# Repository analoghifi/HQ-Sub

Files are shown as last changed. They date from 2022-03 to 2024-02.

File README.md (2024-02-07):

# HQ-Sub  
adjustable\* 5th order (**30 dB/oct.**) subsonic filter  
mono module  
\*(13-53Hz / in 2-3Hz steps / 16 steps)  
  
https://web.archive.org/web/20160324051200/http://thel-audioworld.de/module/Filterzone/HQ-Sub.htm

----  

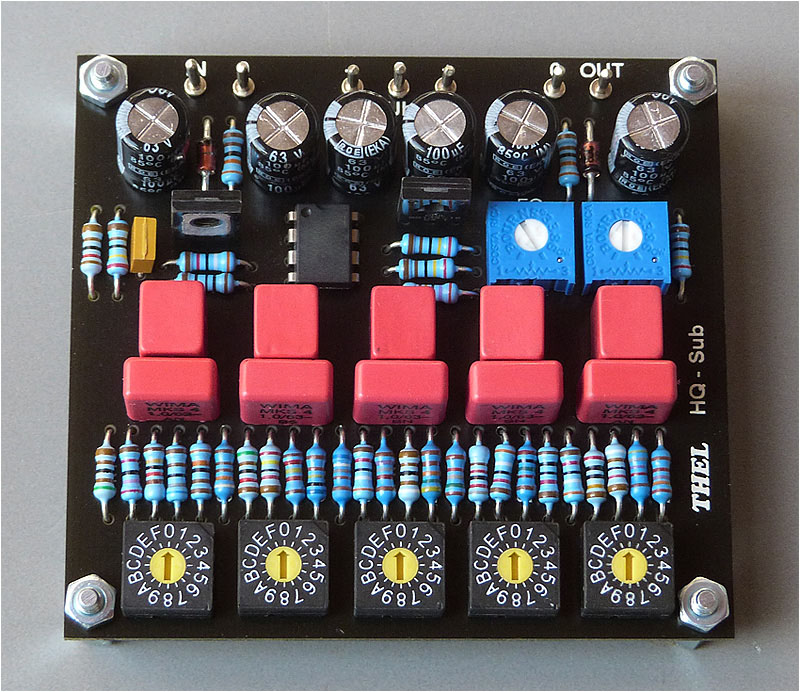
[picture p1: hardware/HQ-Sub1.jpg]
  
  
----  

### Frequency Table:  
* 0: 13Hz
* 1: 15Hz
* 2: 18Hz
* 3: 21Hz
* 4: 23Hz
* 5: 26Hz
* 6: 29Hz
* 7: 31Hz
* 8: 34Hz
* 9: 36Hz
* A: 39Hz
* B: 41Hz
* C: 44Hz
* D: 47Hz
* E: 50Hz
* F: 53Hz  

All 5 switches must always be in the same position (!)  
  
----  
  
### A note on the capacitors used in the original design  
The basic problem is:  
to get meaningful (= not too high) resistance values in this 5th order filter design we want to use 1µF capacitors.  
However, 1µF capacitors are generally not available in the KP film/foil version,  
at least not with a 1% tolerance and/or in suitable small dimensions for this small PCB.  
  
regarding C8-C17 in the original design:  
the 1µF MKS capacitors are paralleled with 22nF KP capacitors  
to compensate the very bad (=very high) dissipation factor (tanδ) of the MKS capacitors  
originally equipped with:  
WIMA MKS4    1µF/63V 10%   (Metallized Polyester (PET))     tanδ=8x10<sup>-3</sup> -> <a href="https://github.com/analoghifi/capacitors/blob/main/audio%20and%20filter%20capacitors/docs/datasheets/dont%20use/PET%20MKS/WIMA_MKS_4__EN.pdf">Datasheet</a>  
WIMA FKP2  0,022µF/63V 5%  (film/foil Polypropylene) tanδ=5x10<sup>-4</sup> -> <a href="https://github.com/analoghifi/capacitors/blob/main/audio%20and%20filter%20capacitors/docs/datasheets/kp/WIMA_FKP_2__NEW_ROHS__EN.pdf">Datasheet (ROHS-version)</a>  
(better old FKP2 version "NOS" without ROHS -> <a href ="https://github.com/analoghifi/capacitors/blob/main/audio%20and%20filter%20capacitors/docs/datasheets/kp/WIMA_FKP_2__OLD_nonROHS__EN.pdf">old Datasheet</a>)  
  
another problem is:  
You have to do a lot of component selection work (matching) when using 10% capacitors because:  
Even while it is not so important that the 5 filter capacitors have exactly 1.00 µF,  
they should at least all have the same value (±1%) among each other  
for this kind of 5th order filter arrangement.  
  
#### better alternative (better tolerance & better tanδ):
use good MKP 1% capacitors (with no additional parallel capacitors = omit C9,C11,C13,C15 and C17)  
**for example:**  
Vishay MKP1839 [MKP1839510161] 1µF/160V 1% axial (metallized Polypropylene) tanδ=4x10<sup>-4</sup> -> <a href="https://github.com/analoghifi/capacitors/blob/main/audio%20and%20filter%20capacitors/docs/datasheets/mkp/vishay_mkp1839.pdf">Datasheet</a> -> buy: https://mou.sr/3OpbFIe     
my KiCad PCB (<a href="/hardware/KiCad/original">/hardware/KiCad/original</a>) is prepared for using this big axial capacitors (10.5mm x 26.5mm) in upright position.  
**or another alternative:**  
Dayton Audio "PMPC-1.0 1.0uF 250V Precision Audio Capacitor" (metallized Polypropylene) with 1% tolerance as well   
-> https://www.daytonaudio.com/product/179/pmpc-1-0-1-0uf-250v-precision-audio-capacitor  
-> https://www.soundimports.eu/en/dayton-audio-pmpc-1-0.html  
-> https://www.parts-express.com/Dayton-Audio-PMPC-1.0-1.0uF-250V-Precision-Audio-Capacitor-027-210  
although not knowing the exact<sup>1</sup> tanδ for this type -> will be measured by me soon ...  
  
<sup>1</sup>(the manufacturer's statement: *"Dissipation Factor [tanδ]: Max 0.001 (0.1%) [10x10<sup>-4</sup>] @ 1 KHz"* is only a general worst case statement for the entire series of these capacitors.)
  
----  
### Kicad projects in this repo:  
* [Thel HQ-Sub](https://github.com/analoghifi/HQ-Sub/tree/main/hardware/KiCad/original) | state: initial release v1.01 | like the original, 1-layer, THT

----

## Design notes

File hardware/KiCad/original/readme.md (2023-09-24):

this is not the original Thel PCB but it's very like\* the original with the following exceptions:  
* more massive ground and power supply PCB tracks  
* using the 2mm gold-plated (lathe made) brass solder pins (the same ones used on the more expensive Thel modules)
* swapped positions for C1<->C5 and C2<->C6
* using a special footprint for the 1µF MKS foil caps (C8,C10,C12,C14,C16), so that you can use bigger (better) MKP axial caps in upright position (in this case: omit C9,C11,C13,C15 and C17)
  
\*(same schematic / same board dimensions / same 1-layer\** layout THT / same THT components in the same places on the board)  
\**(strictly speaking, this KiCad PCB is a two-layer PCB with plated-through holes, but you can also (let) produce it as a classic 1-layer PCB with non-plated holes if you wish, since all the tracks are on the bottom side only)  
    
----  
  
### remarks:  
#### U1:  
instead of [MC33078](https://github.com/analoghifi/HQ-Sub/blob/main/docs/components%20datasheet/MC33078_Motorola.pdf) you can use [LME49720](https://github.com/analoghifi/HQ-Sub/blob/main/docs/components%20datasheet/LME49720.pdf) or [LM4562](https://github.com/analoghifi/HQ-Sub/blob/main/docs/components%20datasheet/LM4562.pdf) (both\* Texas Instruments),  
with slightly better technical data regarding noise and THD.  
\*(these two are 100% identical (even regarding their inner guts))  

----  
  
these are KiCad 6.x projects  
see how to get the proper 3D-Models from here: https://github.com/analoghifi/KiCad-3D-Models

----  
  
use kicanvas.org to view this KiCad project in your browser:  
https://kicanvas.org/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

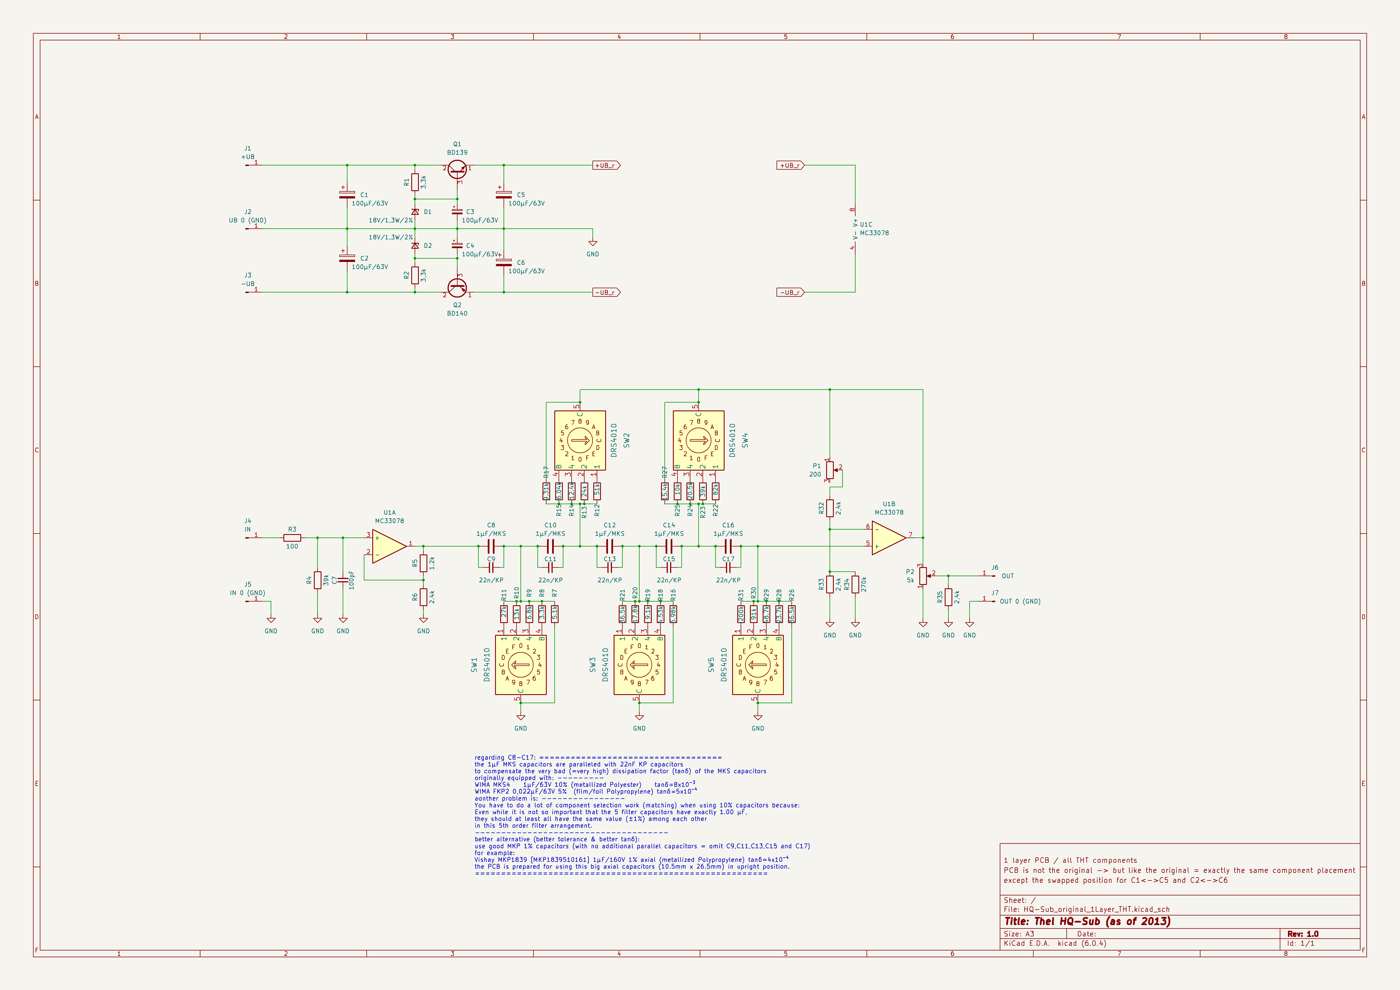
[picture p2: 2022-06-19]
hardware/KiCad/original/HQ-Sub_original_1Layer_THT__sch.png

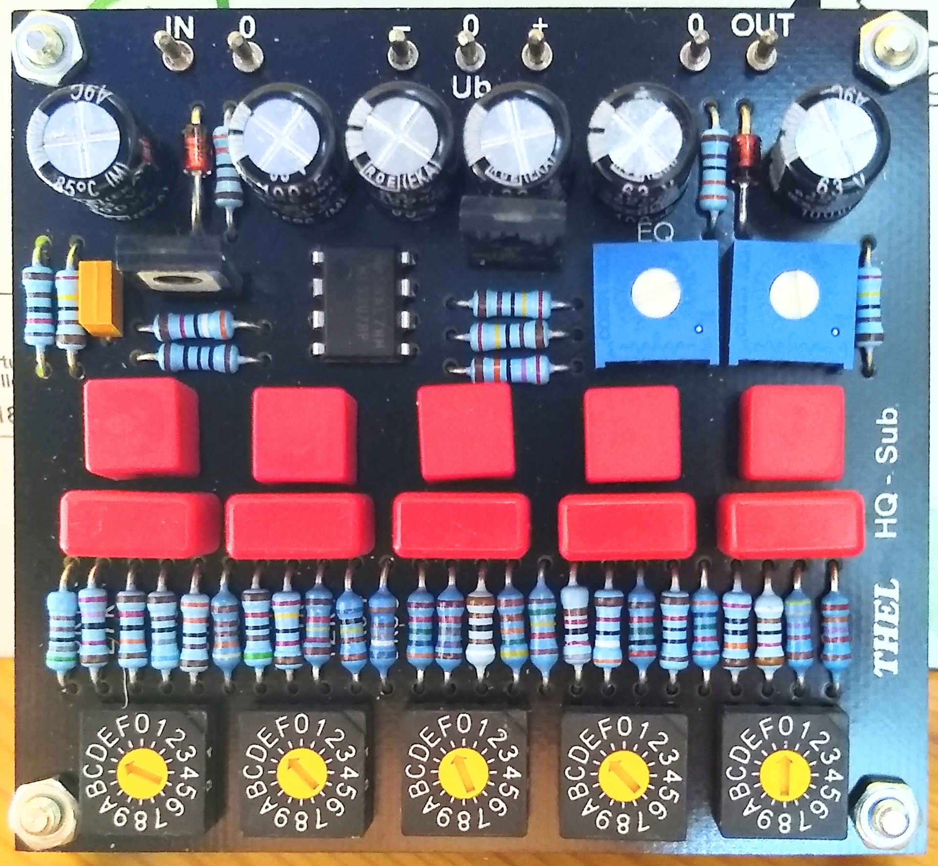
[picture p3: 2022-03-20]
hardware/HQ-Sub_Top (1).jpg

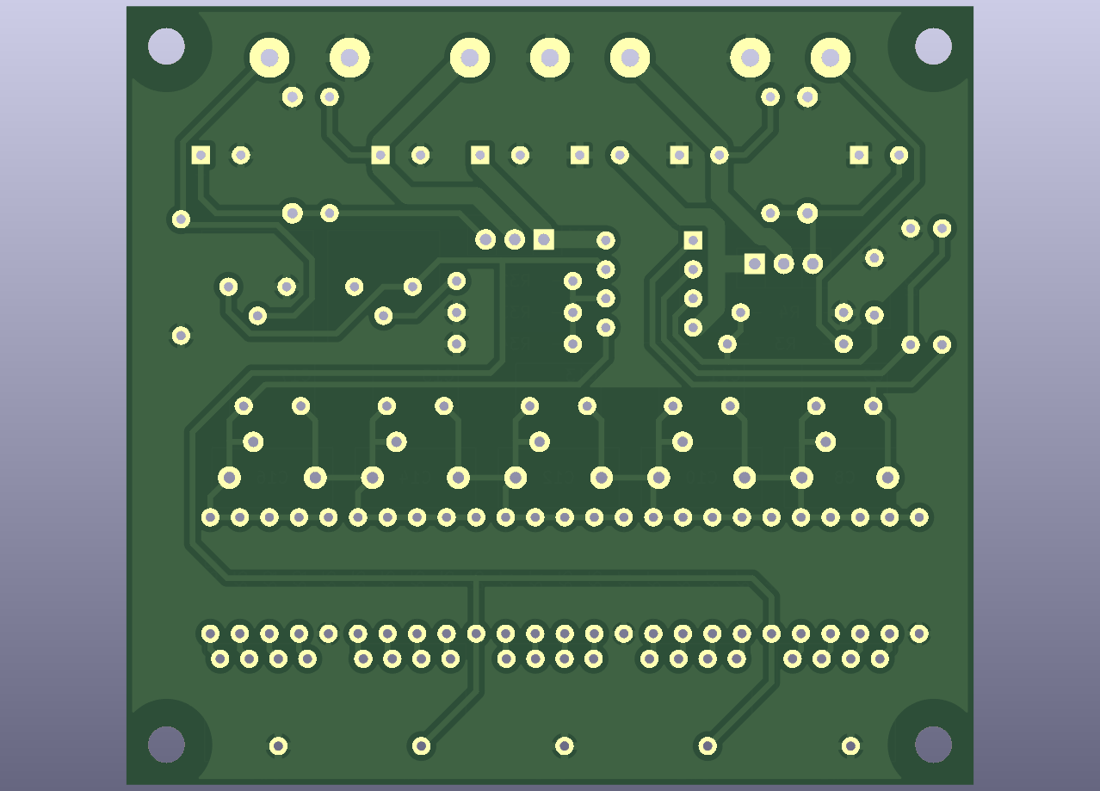
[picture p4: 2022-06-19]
hardware/KiCad/original/HQ-Sub_original_1Layer_THT__bottom.png

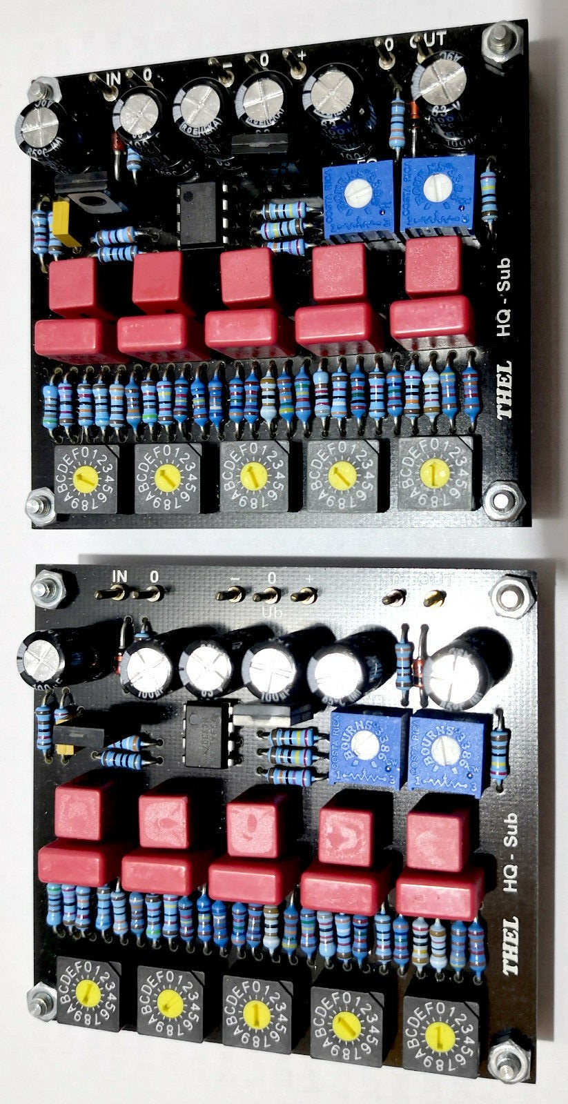
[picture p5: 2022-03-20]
hardware/HQ-Sub_3.jpg

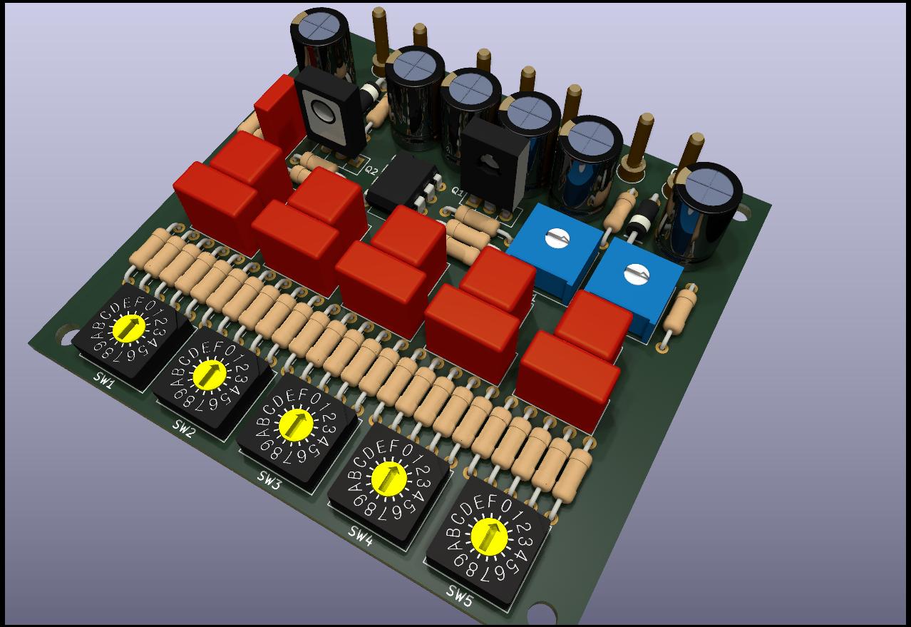
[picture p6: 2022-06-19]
hardware/KiCad/original/HQ-Sub_original_1Layer_THT__3D_normal_caps.jpg

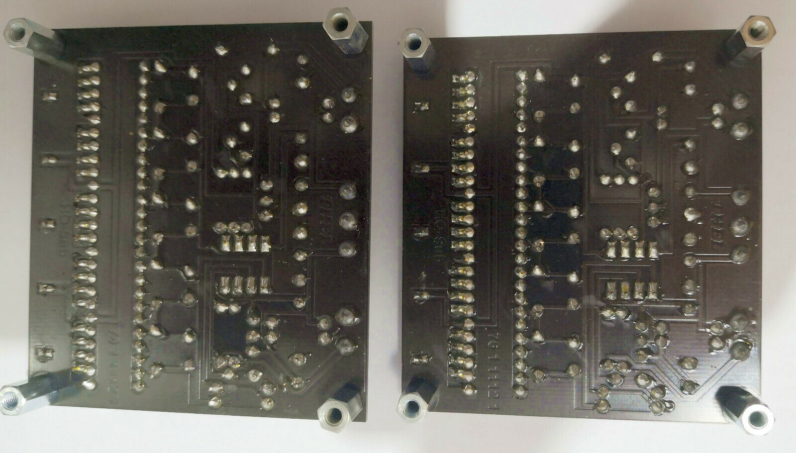
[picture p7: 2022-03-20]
hardware/HQ-Sub_2.jpg

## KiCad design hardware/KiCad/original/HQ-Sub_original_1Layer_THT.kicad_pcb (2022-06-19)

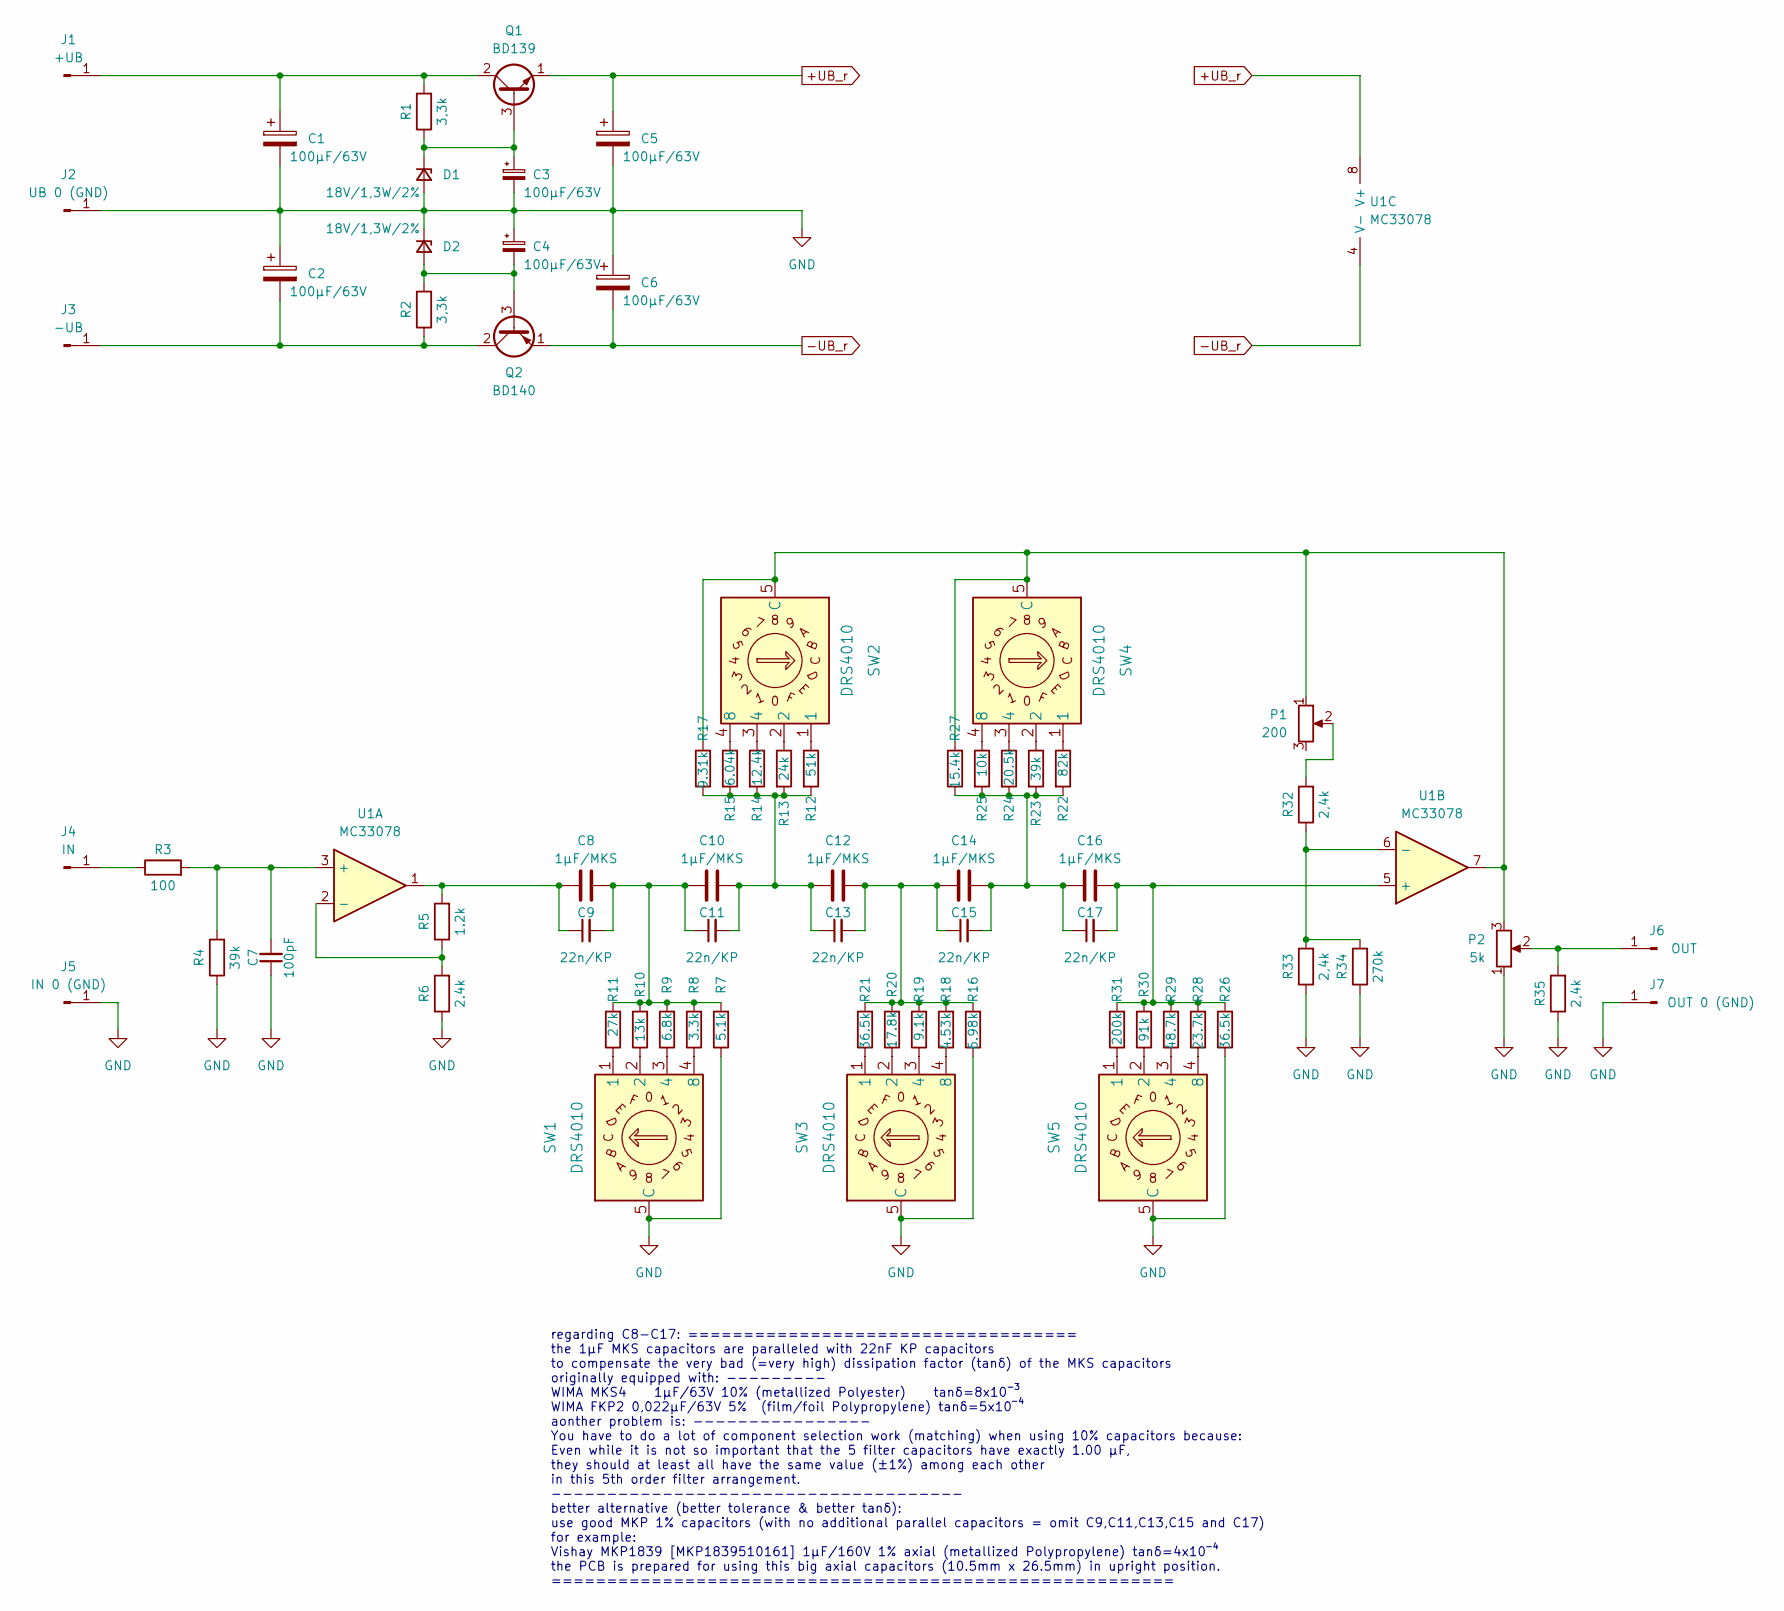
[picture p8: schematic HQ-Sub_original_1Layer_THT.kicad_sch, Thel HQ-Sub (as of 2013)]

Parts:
C1, C2, C3, C4, C5, C6: 100µF/63V; CP_Radial_Black_D8.2mm_H12.5mm_P3.50mm_minimal_silk
C7: 100pF; C_Rect_L7.0mm_W2.5mm_P5.00mm
C8, C10, C12, C14, C16: 1µF/MKS; C_Rect_L10.3mm_W5.0mm_P7.50mm_MKS4
C9, C11, C13, C15, C17: 22n/KP; C_Rect_L7.2mm_W7.2mm_P5.00mm_FKS2_FKP2_MKS2_MKP2
D1, D2: 18V/1,3W/2%; D_DO-41_SOD81_P10.16mm_Horizontal_minSilk
J1: +UB; Loet_Pin_D1.5mm_L14.0mm
J2: UB 0 (GND); Loet_Pin_D1.5mm_L14.0mm
J3: -UB; Loet_Pin_D1.5mm_L14.0mm
J4: IN; Loet_Pin_D1.5mm_L14.0mm
J5: IN 0 (GND); Loet_Pin_D1.5mm_L14.0mm
J6: OUT; Loet_Pin_D1.5mm_L14.0mm
J7: OUT 0 (GND); Loet_Pin_D1.5mm_L14.0mm
P1: 200; Potentiometer_Bourns_3386P_Vertical
P2: 5k; Potentiometer_Bourns_3386P_Vertical
Q1: BD139; TO-126-3_Vertical
Q2: BD140; TO-126-3_Vertical
R1, R2: 3,3k; R_Axial_DIN0207_L6.3mm_D2.5mm_P10.16mm_Horizontal_minSilk
R3: 100; R_Axial_DIN0207_L6.3mm_D2.5mm_P10.16mm_Horizontal_minSilk
R4: 39k; R_Axial_Short_L6.3mm_D2.5mm_P9.0mm_Horiz_minSilk
R5: 1.2k; R_Axial_DIN0207_L6.3mm_D2.5mm_P10.16mm_Horizontal_minSilk
R6: 2.4k; R_Axial_DIN0207_L6.3mm_D2.5mm_P10.16mm_Horizontal_minSilk
R7: 5.1k; R_Axial_DIN0207_L6.3mm_D2.5mm_P10.16mm_Horizontal_minSilk
R8: 3.3k; R_Axial_DIN0207_L6.3mm_D2.5mm_P10.16mm_Horizontal_minSilk
R9: 6.8k; R_Axial_DIN0207_L6.3mm_D2.5mm_P10.16mm_Horizontal_minSilk
R10: 13k; R_Axial_DIN0207_L6.3mm_D2.5mm_P10.16mm_Horizontal_minSilk
R11: 27k; R_Axial_DIN0207_L6.3mm_D2.5mm_P10.16mm_Horizontal_minSilk
R12: 51k; R_Axial_DIN0207_L6.3mm_D2.5mm_P10.16mm_Horizontal_minSilk
R13: 24k; R_Axial_DIN0207_L6.3mm_D2.5mm_P10.16mm_Horizontal_minSilk
R14: 12.4k; R_Axial_DIN0207_L6.3mm_D2.5mm_P10.16mm_Horizontal_minSilk
R15: 6.04k; R_Axial_DIN0207_L6.3mm_D2.5mm_P10.16mm_Horizontal_minSilk
R16: 6.98k; R_Axial_DIN0207_L6.3mm_D2.5mm_P10.16mm_Horizontal_minSilk
R17: 9.31k; R_Axial_DIN0207_L6.3mm_D2.5mm_P10.16mm_Horizontal_minSilk
R18: 4.53k; R_Axial_DIN0207_L6.3mm_D2.5mm_P10.16mm_Horizontal_minSilk
R19: 9.1k; R_Axial_DIN0207_L6.3mm_D2.5mm_P10.16mm_Horizontal_minSilk
R20: 17.8k; R_Axial_DIN0207_L6.3mm_D2.5mm_P10.16mm_Horizontal_minSilk
R21, R26: 36.5k; R_Axial_DIN0207_L6.3mm_D2.5mm_P10.16mm_Horizontal_minSilk
R22: 82k; R_Axial_DIN0207_L6.3mm_D2.5mm_P10.16mm_Horizontal_minSilk
R23: 39k; R_Axial_DIN0207_L6.3mm_D2.5mm_P10.16mm_Horizontal_minSilk
R24: 20.5k; R_Axial_DIN0207_L6.3mm_D2.5mm_P10.16mm_Horizontal_minSilk
R25: 10k; R_Axial_DIN0207_L6.3mm_D2.5mm_P10.16mm_Horizontal_minSilk
R27: 15.4k; R_Axial_DIN0207_L6.3mm_D2.5mm_P10.16mm_Horizontal_minSilk
R28: 23.7k; R_Axial_DIN0207_L6.3mm_D2.5mm_P10.16mm_Horizontal_minSilk
R29: 48.7k; R_Axial_DIN0207_L6.3mm_D2.5mm_P10.16mm_Horizontal_minSilk
R30: 91k; R_Axial_DIN0207_L6.3mm_D2.5mm_P10.16mm_Horizontal_minSilk
R31: 200k; R_Axial_DIN0207_L6.3mm_D2.5mm_P10.16mm_Horizontal_minSilk
R32, R33, R35: 2,4k; R_Axial_DIN0207_L6.3mm_D2.5mm_P10.16mm_Horizontal_minSilk
R34: 270k; R_Axial_DIN0207_L6.3mm_D2.5mm_P10.16mm_Horizontal_minSilk
SW1, SW2, SW3, SW4, SW5: DRS4010; DRS_3016_4010
U1: MC33078; DIP-8_W7.62mm

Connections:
+UB_r: C5.1, Q1.1 (E), U1.8 (V+)
-UB_r: C6.2, Q2.1 (E), U1.4 (V-)
GND: C1.2, C2.1, C3.2, C4.1, C5.2, C6.1, C7.1, D1.2 (A), D2.1 (K), J2.1, J5.1, J7.1, P2.1, R4.1, R6.1, R7.1, R16.1, R26.1, R33.1, R34.1, R35.1, SW1.5 (C), SW3.5 (C), SW5.5 (C)
unnamed: C1.1, J1.1, Q1.2 (C), R1.2
unnamed: C2.2, J3.1, Q2.2 (C), R2.1
unnamed: C3.1, D1.1 (K), Q1.3 (B), R1.1
unnamed: C4.2, D2.2 (A), Q2.3 (B), R2.2
unnamed: C7.2, R3.2, R4.2, U1.3 (+)
unnamed: C8.2, C9.1, R5.2, U1.1
unnamed: C8.1, C9.2, C10.2, C11.1, R7.2, R8.2, R9.2, R10.2, R11.2
unnamed: C12.1, C13.2, C14.2, C15.1, R16.2, R18.2, R19.2, R20.2, R21.2
unnamed: C14.1, C15.2, C16.2, C17.1, R22.2, R23.2, R24.2, R25.2, R27.1
unnamed: C16.1, C17.2, R26.2, R28.2, R29.2, R30.2, R31.2, U1.5 (+)
unnamed: J4.1, R3.1
unnamed: J6.1, P2.2, R35.2
unnamed: R5.1, R6.2, U1.2 (-)
unnamed: R8.1, SW1.4 (8)
unnamed: R9.1, SW1.3 (4)
unnamed: R10.1, SW1.2
unnamed: R11.1, SW1.1
unnamed: R12.1, SW2.1
unnamed: C10.1, C11.2, C12.2, C13.1, R12.2, R13.2, R14.2, R15.2, R17.1
unnamed: R13.1, SW2.2
unnamed: R14.1, SW2.3 (4)
unnamed: R15.1, SW2.4 (8)
unnamed: P1.1, P2.3, R17.2, R27.2, SW2.5 (C), SW4.5 (C), U1.7
unnamed: R18.1, SW3.4 (8)
unnamed: R19.1, SW3.3 (4)
unnamed: R20.1, SW3.2
unnamed: R21.1, SW3.1
unnamed: R22.1, SW4.1
unnamed: R23.1, SW4.2
unnamed: R24.1, SW4.3 (4)
unnamed: R25.1, SW4.4 (8)
unnamed: R28.1, SW5.4 (8)
unnamed: R29.1, SW5.3 (4)
unnamed: R30.1, SW5.2
unnamed: R31.1, SW5.1
unnamed: R32.1, R33.2, R34.2, U1.6 (-)
unnamed: P1.2, R32.2

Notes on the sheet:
regarding C8-C17: =================================== the 1µF MKS capacitors are paralleled with 22nF KP capacitors to compensate the very bad (=very high) dissipation factor (tanδ) of the MKS capacitors originally equipped with: --------- WIMA MKS4 1µF/63V 10% (metallized Polyester) tanδ=8x10 WIMA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

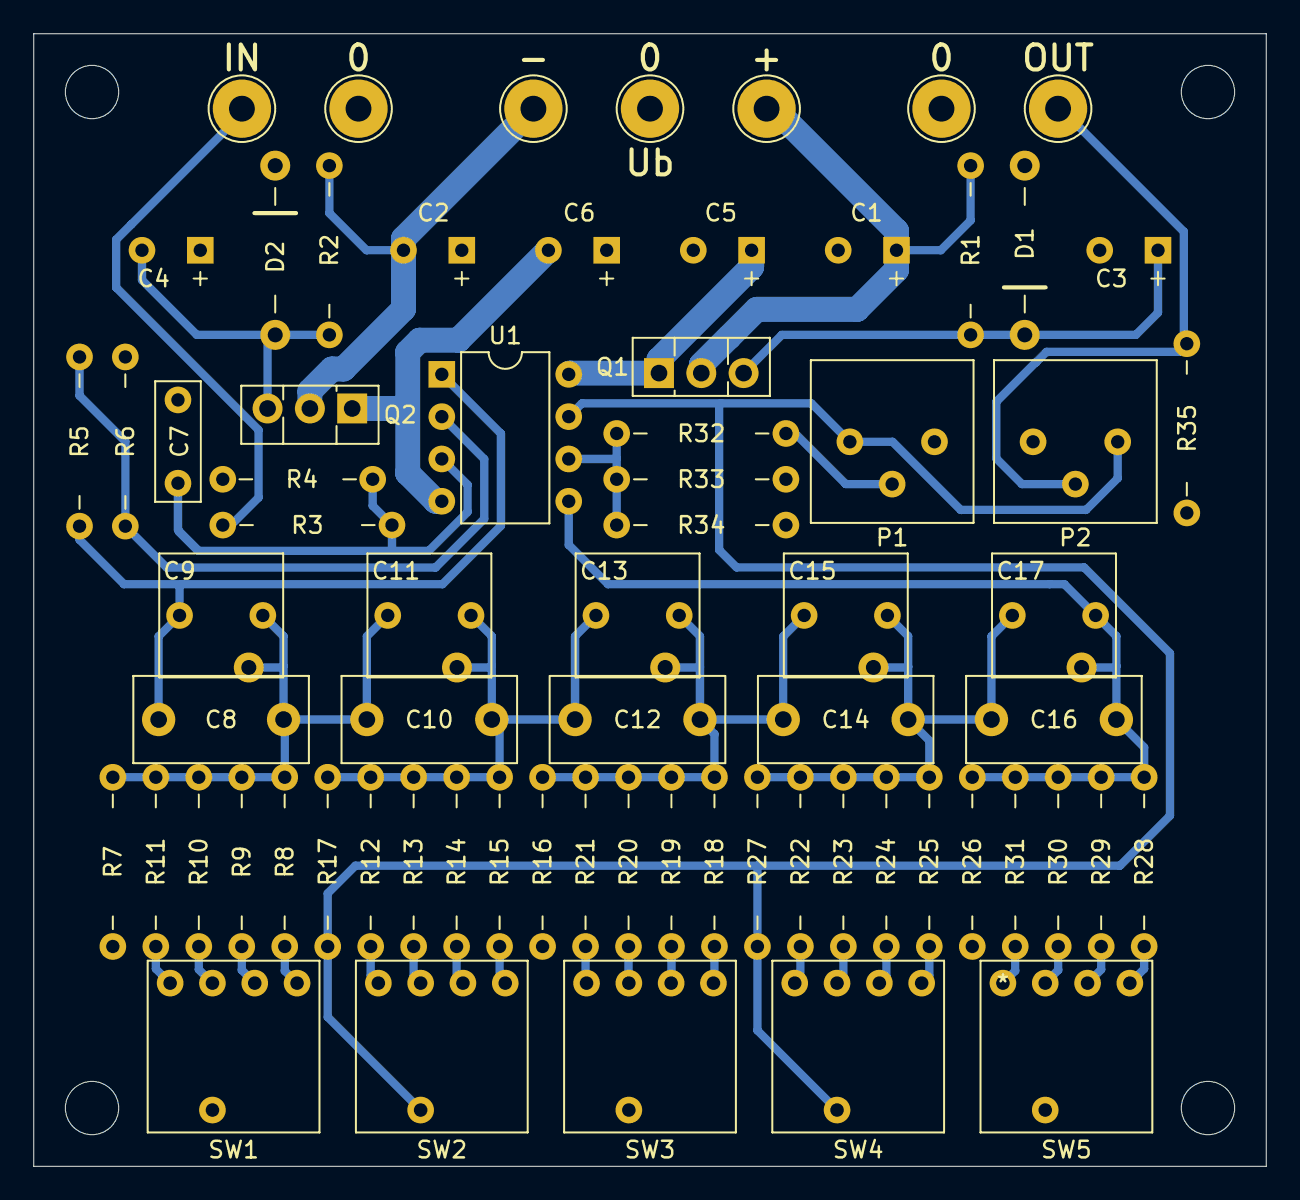
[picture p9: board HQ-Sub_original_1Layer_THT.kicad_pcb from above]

Board: 2 copper layers, 74.0 x 68.0 mm, 71 parts (0 on the bottom side), 40 nets.
